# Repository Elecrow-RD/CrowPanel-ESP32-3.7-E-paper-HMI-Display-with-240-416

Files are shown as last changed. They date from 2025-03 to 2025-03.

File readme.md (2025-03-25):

### 1, Product picture

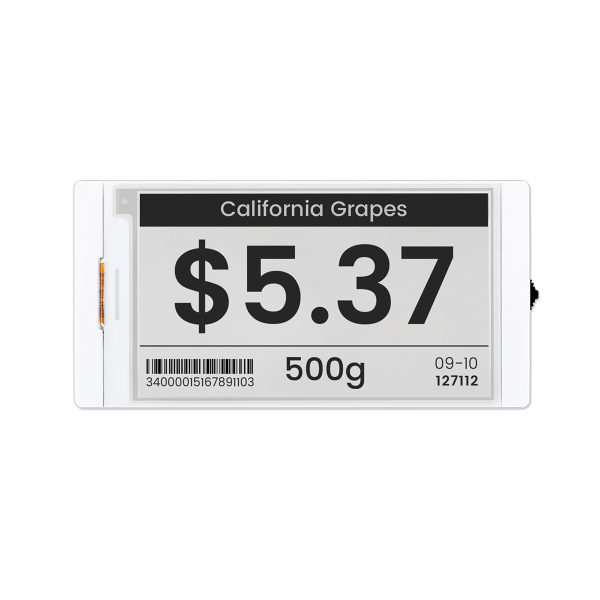
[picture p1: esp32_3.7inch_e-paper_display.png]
esp32_3.7inch_e-paper_display


### 2, Product version number

| | Hardware | Software | Remark |
| ---- | --- | --- | --- |
| 1 | V1.0 | V1.0 | latest |

### 3, product information

  - # Display Module Specifications

    - **Size**: 3.7 inch

    - **MCU**: ESP32-S3-WROOM-1-N8R8, up to 240 MHz

    - **Flash**: 8 MB

    - **PSRAM**: 8 MB

    - **Material**: Active Matrix Electrophoretic Display (AM EPD)

    - **Driver Chip**: UC8253

    - **Resolution**: 240(H)*416(V) Pixel

    - **Pixel Pitch**: 0.196*0.196

    - **Viewing Angle**: Full Viewing Angle

    - **Communication Interface**: 3-/4-wire SPI, default 4-wire SPI
  
    - **Interface**:
      
      - UART0 x1
      - BAT x1
      - GPIO x1
    
      - TF Card x1
    - **Button**:
      - Dial Switch x1
      - Menu Button  x1
      - Back Button x1
      - REST Button  x1
  
      - BOOT Button x1
- **Development Environment**: Arduino IDE、ESP IDF、MicroPython
    
- **Display Color**: Black and white
    
- **Refresh Mode**: Partial refresh (saves more power)
    
- **Display Operation Voltage**: 2.2~3.7V
    
- **Case**: White Acrylic Case
    
  - **Operation Temperature**: -0~50℃
    
  - **Storage Temperature**: -25~70℃
    
    - **Active Area**: 47.04(H)\*81.54(L) (H*L)

### 4, Use the driver module

| Name | dependency library |
| --- | --- |
| UC8253 | EPD<br />version=1.0.0 |

### 5,Quick Start

##### Arduino IDE starts

1.Download the library files used by this product to the 'libraries' folder.

C:\Users\Documents\Arduino\libraries\



2.Open the Arduino IDE

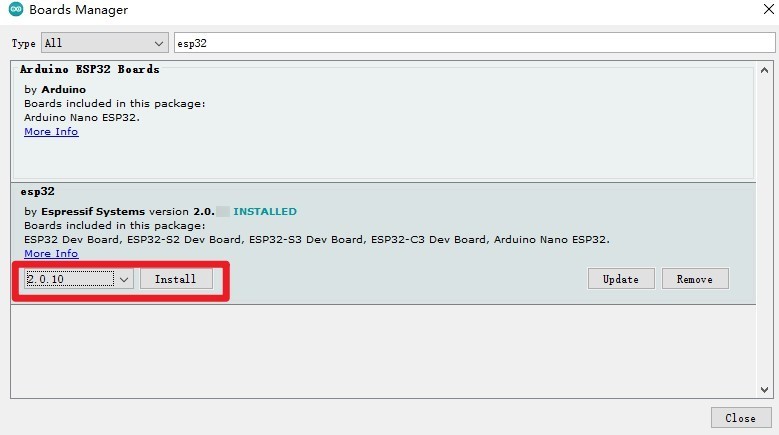
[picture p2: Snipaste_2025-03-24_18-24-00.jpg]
Snipaste_2025-03-24_18-24-00


3.Open the code configuration environment and burn it

setting

### 6,Folder structure.

|--3D file： Contains 3D model files (.stp) for the hardware. These files can be used for visualization, enclosure design, or integration into CAD software.

|--Datasheet: Includes datasheets for components used in the project, providing detailed specifications, electrical characteristics, and pin configurations.

|--Eagle_SCH&PCB: Contains **Eagle CAD** schematic (`.sch`) and PCB layout (`.brd`) files. These are used for circuit design and PCB manufacturing.

|--example: Provides example code and projects to demonstrate how to use the hardware and libraries. These examples help users get started quickly.

|--factory_firmware: Stores pre-compiled factory firmware that can be directly flashed onto the device. This ensures the device runs the default functionality.

|--factory_sourcecode: Contains the source code for the factory firmware, allowing users to modify and rebuild the firmware as needed.

### 7,Pin definition

#define SCK 12

#define MOSI 11

#define RES 47

#define DC 46

#define CS 45

#define BUSY 48

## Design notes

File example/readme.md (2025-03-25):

**Arduino**: This folder contains sample programs for the Arduino platform, which is known for its ease of use and versatility in creating interactive electronic projects.

#### NOTE!!!:When running this program , you need to download the officially provided libraries and place them in the libraries of arduino. esp32 version needs to be 2.0.10 the version of the libraries is the same as the officially provided version.

Link to the corresponding course wiki:https://www.elecrow.com/wiki/CrowPanel_ESP32_E-Paper_3.7-inch_Arduino_Tutorial.html

Video Tutorial Links：https://www.youtube.com/watch?v=smDFHRxDYdw

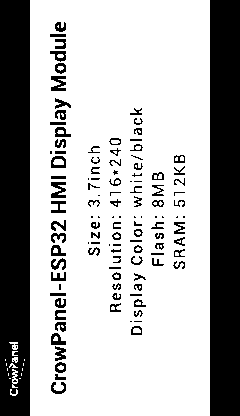
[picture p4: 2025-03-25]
factory_sourecode/3.7_tow/pic/IRAD_UI_3_7_参数介绍.bmp

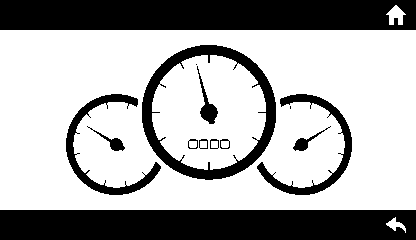
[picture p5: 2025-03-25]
factory_sourecode/3.7_tow/pic/new/NEW_UI_3-7_BW_img-03.bmp

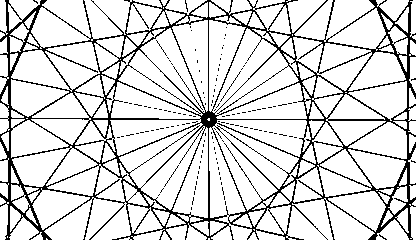
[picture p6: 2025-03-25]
factory_sourecode/3.7_tow/pic/IRAD_UI_3_7/IRAD_UI_3_7_图片案例-06.bmp

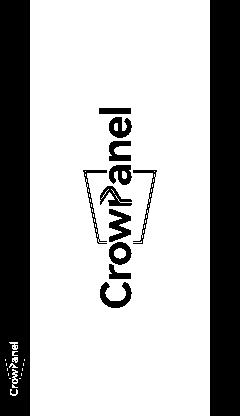
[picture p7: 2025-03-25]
factory_sourecode/3.7_tow/pic/IRAD_UI_3_7_开机界面.bmp

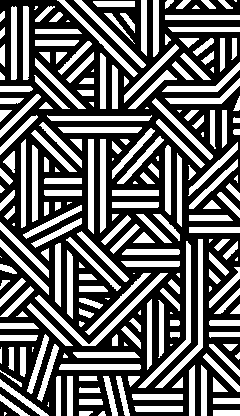
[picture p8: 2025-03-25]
factory_sourecode/3.7_tow/pic/IRAD_UI_3_7_图片案例-08.bmp

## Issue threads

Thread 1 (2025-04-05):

Wrong comments in TF example

05k4rausdertonne, 2025-04-05:
in the file example/arduino/Examples/3.7_TF/3.7_TF.ino on line 21-23 it says:
```.cpp
 // Initialize the screen backlight pin.
  pinMode(42, OUTPUT);
  digitalWrite(42, HIGH);  // Set the screen backlight pin to high to turn on the backlight.
```
however it should instead be

```.cpp
 // Initialize the TF card control pin.
  pinMode(42, OUTPUT);
  digitalWrite(42, HIGH);  // Set the TF card control pin to high to turn on the TF card.
```

since according to the schematic of the board io 42 is connected to TF_3.3_CTL

this cost me a whole day of error hunting btw. (because i'm stupid) so please update the code accordingly :)

Regards

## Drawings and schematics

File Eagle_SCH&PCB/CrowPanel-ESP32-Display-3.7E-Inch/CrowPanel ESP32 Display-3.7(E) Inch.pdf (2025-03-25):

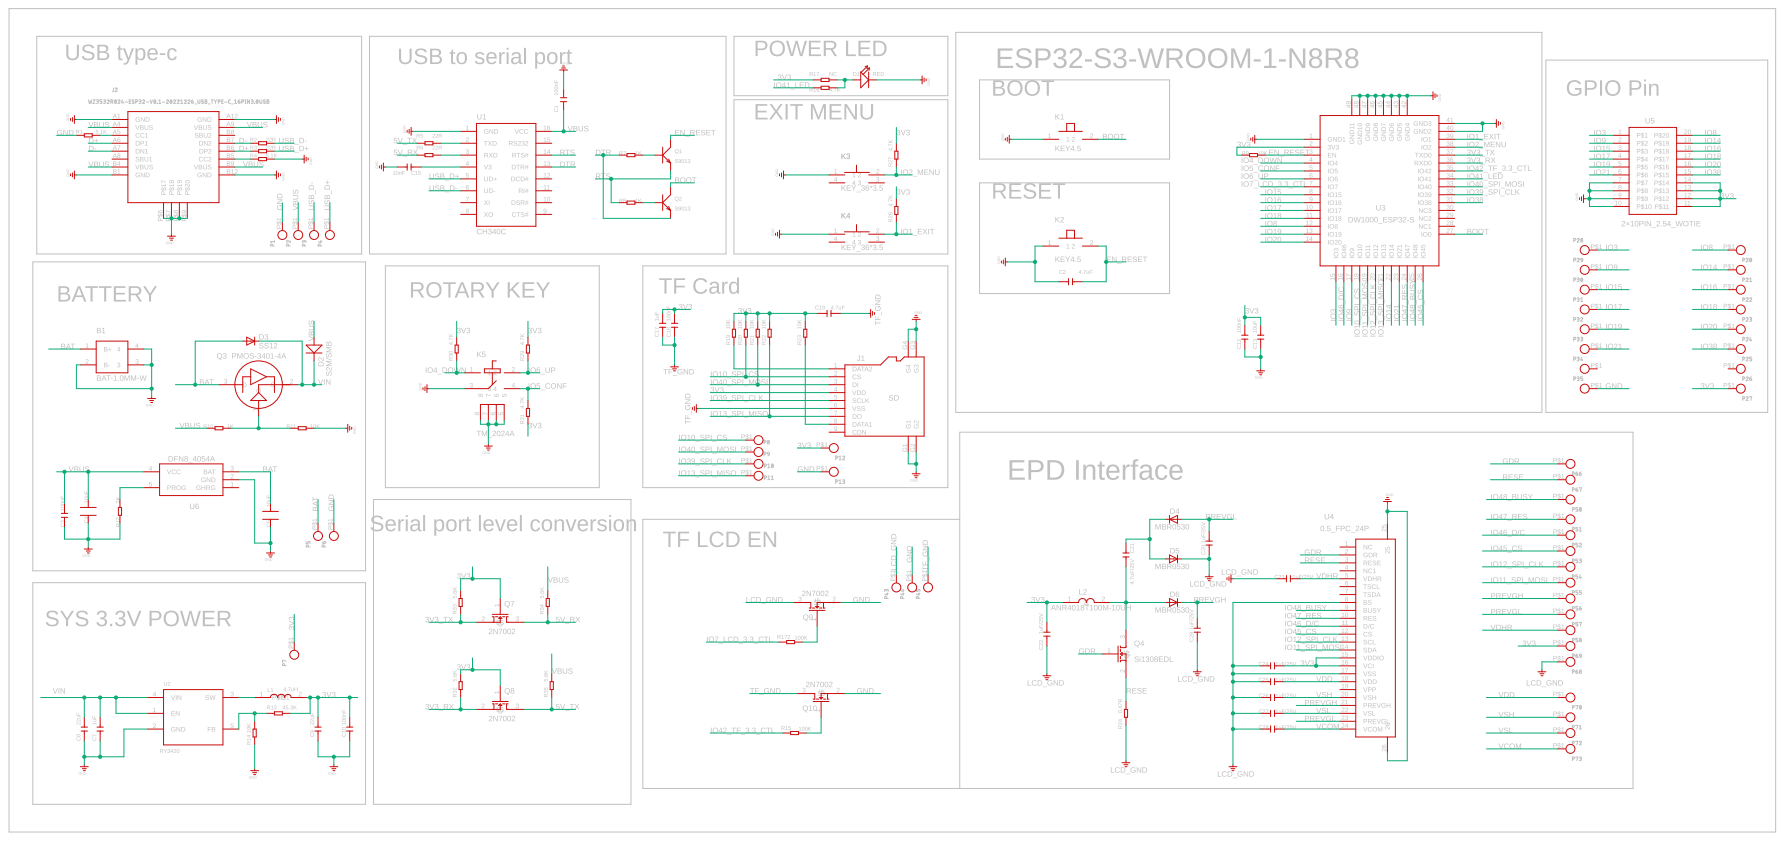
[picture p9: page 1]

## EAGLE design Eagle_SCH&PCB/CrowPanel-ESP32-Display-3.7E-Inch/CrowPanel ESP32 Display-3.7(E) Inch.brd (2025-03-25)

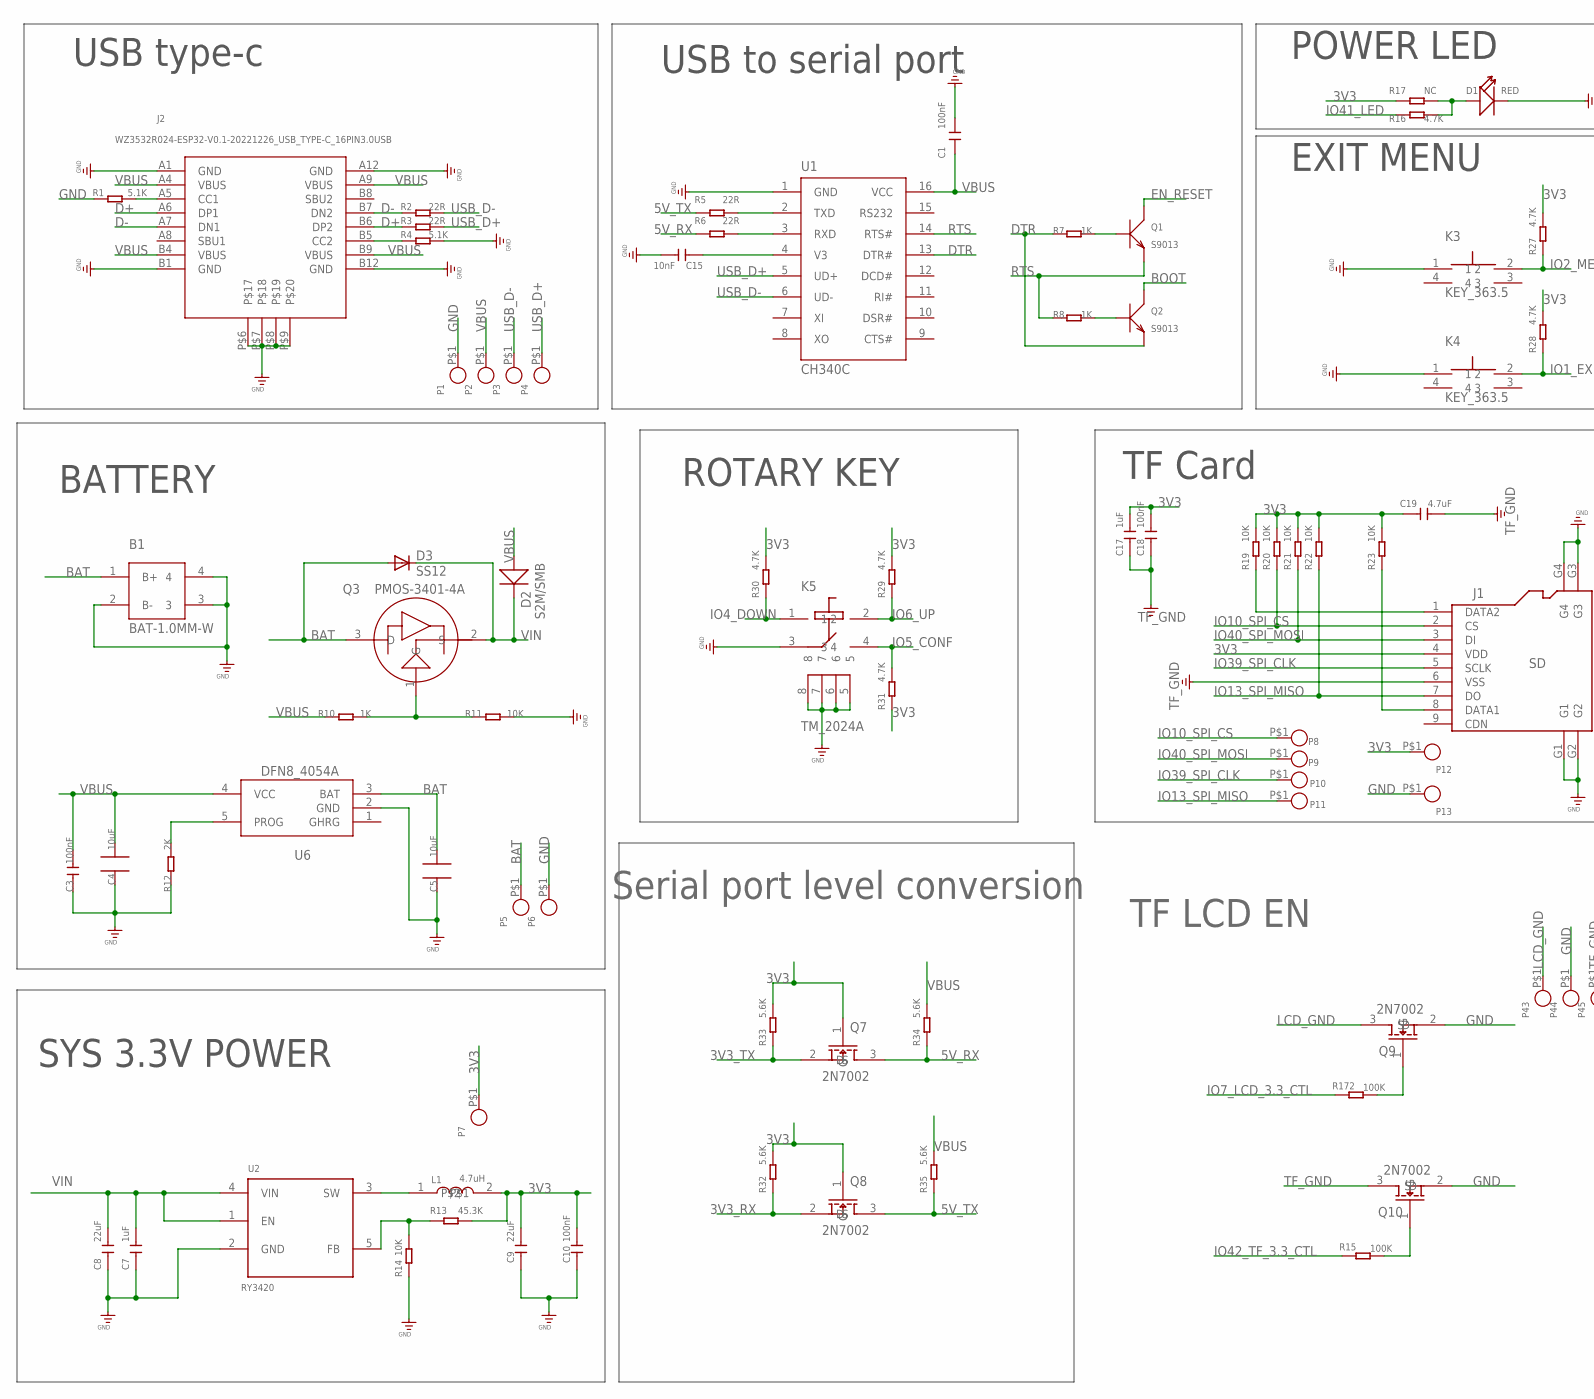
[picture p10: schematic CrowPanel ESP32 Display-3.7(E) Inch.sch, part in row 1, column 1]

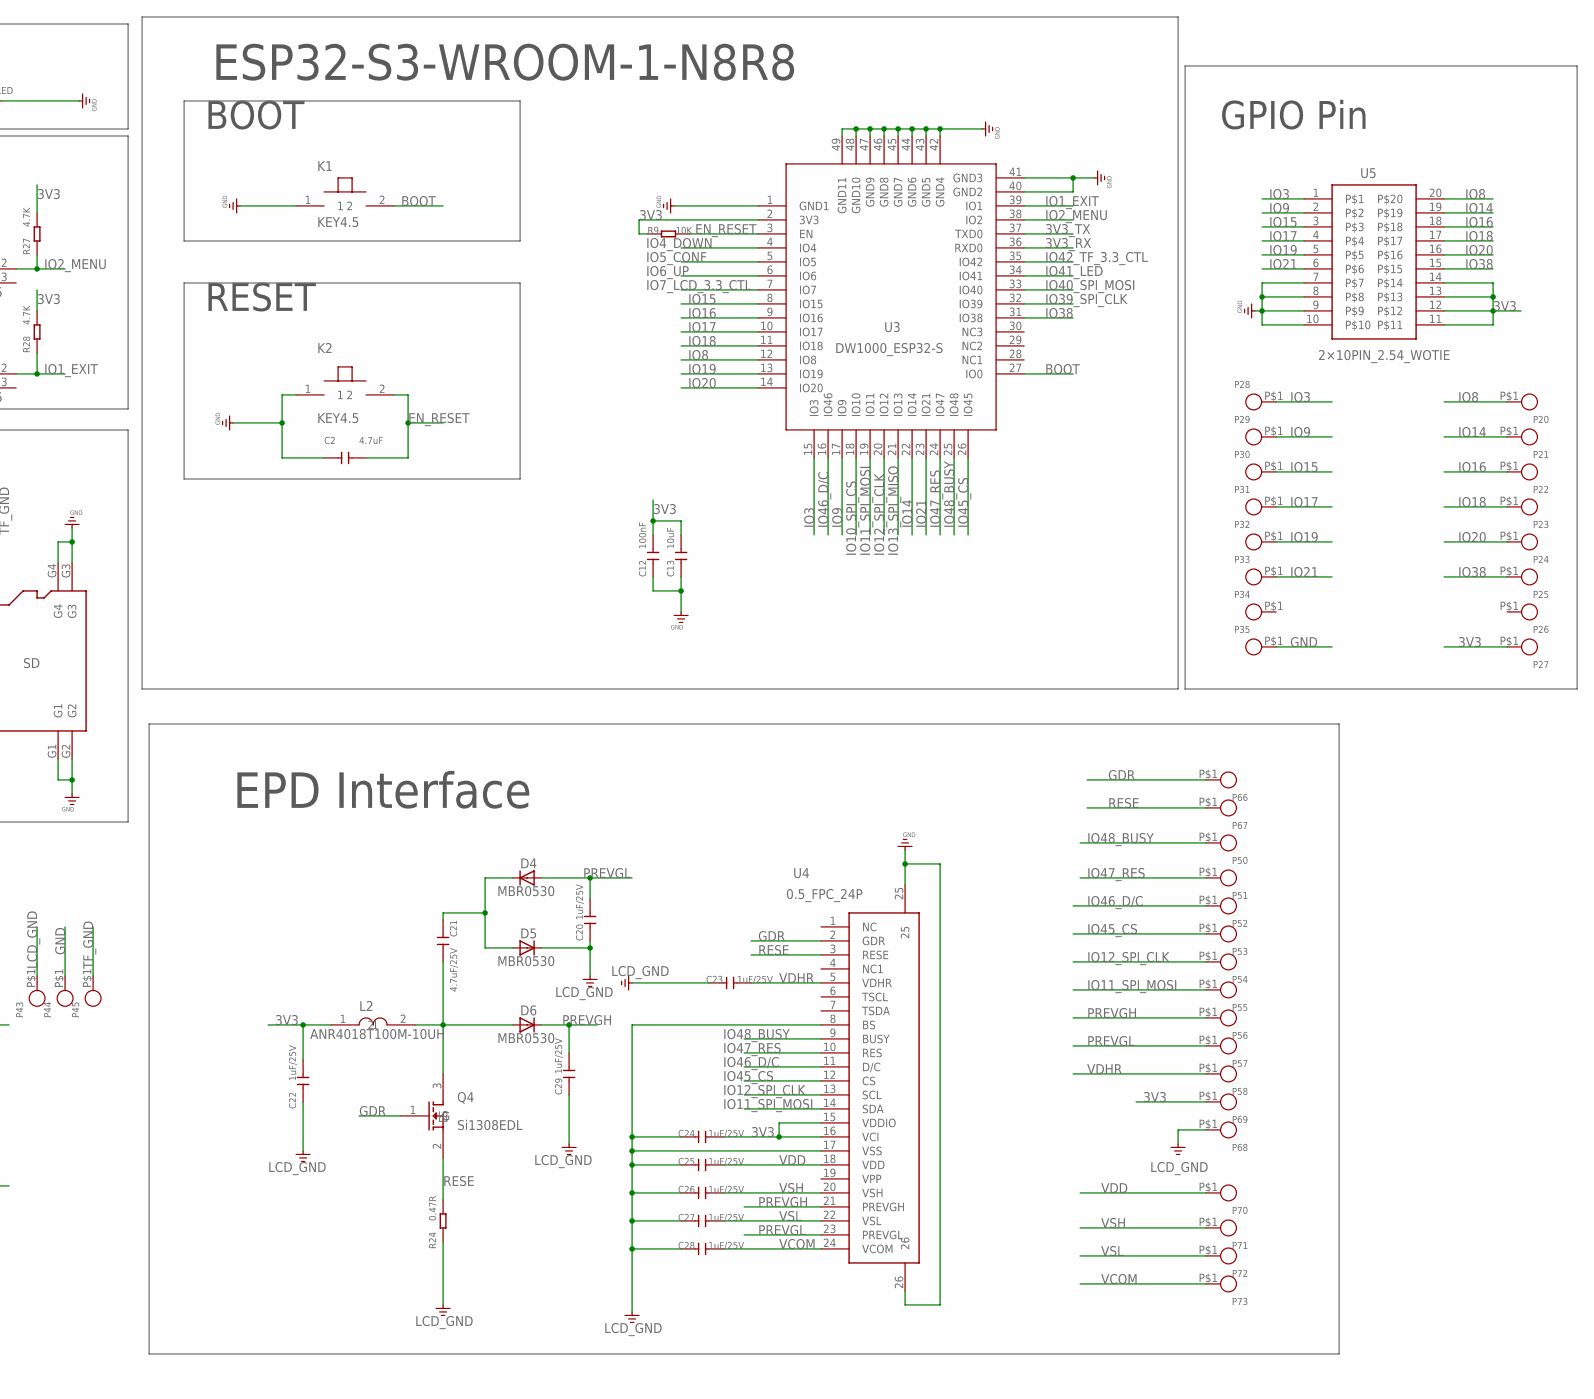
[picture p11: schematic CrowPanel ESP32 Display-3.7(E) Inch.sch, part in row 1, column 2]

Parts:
B1: BAT-1.0MM-W; SH1.0MM-W
C1: 100nF; 0603
C2: 4.7uF; A_XBJ_0603
C3, C12, C18: 100nF; A9G_DISCRETE_C0603
C4, C5: 10uF; CPT_SMD_0805_S
C7: 1uF; A_XBJ_0603
C8, C9: 22uF; A_XBJ_0805
C10: 100nF; A_XBJ_0603
C13: 10uF; A9G_DISCRETE_C0603
C15: 10nF; A_XBJ_0603
C17: 1uF; A9G_DISCRETE_C0603
C19: 4.7uF; A9G_DISCRETE_C0603
C20, C22, C23, C24, C25, C26, C27, C28, C29: 1uF/25V; A9G_DISCRETE_C0603
C21: 4.7uF/25V; A9G_DISCRETE_C0603
D1: RED; A_XBJ_DISCRETE_LED-0603
D2: S2M/SMB; DO-214AB_214AB
D3: SS12; DIODE_DO-214AC
D4, D5, D6: MBR0530; DIODE_SOD123
J1: SD; CONNECTOR_9P-SMD-W/-RING
J2: WZ3532R024-ESP32-V0.1-20221226_USB_TYPE-C_16PIN3.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; WZ3532R024-ESP32-V0.1-20221226_KEVIN_3.0TYPEC-SMD
K1, K2: KEY4.5; KEY-4.5
K3, K4: KEY_363.5; KEY_3*6*3.5
K5: TM_2024A
L1: 4.7uH; WZ2432R028-ESP32-V1.2-20231108_CD54_CD54
L2: ANR4018T100M-10UH; ANR4018
P1, P2, P3, P4, P5, P6, P7, P8, P9, P10, P11, P12, P13, P20, P21, P22, P23, P24, P25, P26, P27, P28, P29, P30, P31, P32, P33, P34, P35, P43, P44, P45, P50, P51, P52, P53, P54, P55, P56, P57, P58, P66, P67, P68, P69, P70, P71, P72, P73: CROWPI_POW_PADPAD-1.0MM; CROWPI_POW_PAD-1.0MM
Q1, Q2: S9013; DISCRETE_SOT23$1
Q3: PMOS-3401-4A; DFN8_SOT-23
Q4: Si1308EDL; SOT-323_W
Q7, Q8, Q9, Q10: 2N7002; SOT23-3_W
R1, R4: 5.1K; R0603
R2, R3, R5, R6: 22R; R0603
R7, R8, R10: 1K; A9G_DISCRETE_R0603
R9, R11, R14, R19, R20, R21, R22, R23: 10K; A9G_DISCRETE_R0603
R12: 2K; A9G_DISCRETE_R0603
R13: 45.3K; A9G_DISCRETE_R0603
R15, R172: 100K; R0603
R16, R27, R28, R29, R30, R31: 4.7K; A9G_DISCRETE_R0603
R17: NC; A9G_DISCRETE_R0603
R24: 0.47R; A9G_DISCRETE_R0603
R32, R33, R34, R35: 5.6K; DISCRETE_R0603
U1: CH340C; A_XBJ_SOP-16
U2: RY3420; CROWBOT_-V1.0-20220525_A_XBJ_SOT23-5
U3: DW1000_ESP32-S; DW1000_ESP32-S3
U4: 0.5_FPC_24P
U5: 2×10PIN_2.54_WOTIE; 2*10PIN_2.54_WOTIE
U6: DFN8_4054A; DFN8_SOP23-5

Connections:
3V3: C9.2, C10.2, C12.2, C13.2, C17.2, C18.2, C19.2, C22.2, C24.1, J1.4 (VDD), L1.2, L2.1, P7.P$1, P12.P$1, P27.P$1, P69.P$1, Q7.1 (G), Q8.1 (G), R9.1, R13.2, R17.1, R19.2, R20.2, R21.2, R22.2, R23.2, R27.2, R28.2, R29.2, R30.2, R31.1, R32.2, R33.2, U3.2 (3V3), U4.15 (VDDIO), U4.16 (VCI), U5.11, U5.12, U5.13, U5.14
3V3_RX: Q8.2 (S), R32.1, U3.36 (RXD0)
3V3_TX: Q7.2 (S), R33.1, U3.37 (TXD0)
5V_RX: Q7.3 (D), R6.1, R34.1
5V_TX: Q8.3 (D), R5.1, R35.1
BAT: B1.1 (B+), C5.2, D3.A, P5.P$1, Q3.3 (D), U6.3 (BAT)
BOOT: K1.2, Q2.3 (C), U3.27 (IO0)
D+: J2.A6 (DP1), J2.B6 (DP2), R3.1
D-: J2.A7 (DN1), J2.B7 (DN2), R2.1
DTR: Q2.2 (E), R7.1, U1.13 (DTR#)
EN_RESET: C2.2, K2.2, Q1.3 (C), R9.2, U3.3 (EN)
GDR: P66.P$1, Q4.1 (G), U4.2 (GDR)
GND: B1.2 (B-), B1.3, B1.4, C1.2, C2.1, C3.1, C4.1, C5.1, C7.1, C8.1, C9.1, C10.1, C12.1, C13.1, C15.2, D1.-, J1.G1, J1.G2, J1.G3, J1.G4, J2.A1 (GND), J2.A12 (GND), J2.B1 (GND), J2.B12 (GND), J2.P$6, J2.P$7, J2.P$8, J2.P$9, K1.1, K2.1, K3.1, K4.1, K5.3, K5.5, K5.6, K5.7, K5.8, P1.P$1, P6.P$1, P13.P$1, P35.P$1, P44.P$1, Q9.2 (S), Q10.2 (S), R1.1, R4.2, R11.2, R12.1, R14.1, U1.1 (GND), U2.2 (GND), U3.1 (GND1), U3.40 (GND2), U3.41 (GND3), U3.42 (GND4), U3.43 (GND5), U3.44 (GND6), U3.45 (GND7), U3.46 (GND8), U3.47 (GND9), U3.48 (GND10), U3.49 (GND11), U4.25, U4.26, U5.7, U5.8, U5.9, U5.10, U6.2 (GND)
IO1_EXIT: K4.2, R28.1, U3.39 (IO1)
IO2_MENU: K3.2, R27.1, U3.38 (IO2)
IO3: P28.P$1, U3.15 (IO3), U5.1
IO4_DOWN: K5.1, R30.1, U3.4 (IO4)
IO5_CONF: K5.4, R31.2, U3.5 (IO5)
IO6_UP: K5.2, R29.1, U3.6 (IO6)
IO7_LCD_3.3_CTL: R172.1, U3.7 (IO7)
IO8: P20.P$1, U3.12 (IO8), U5.20
IO9: P29.P$1, U3.17 (IO9), U5.2
IO10_SPI_CS: J1.2 (CS), P8.P$1, R20.1, U3.18 (IO10)
IO11_SPI_MOSI: P55.P$1, U3.19 (IO11), U4.14 (SDA)
IO12_SPI_CLK: P54.P$1, U3.20 (IO12), U4.13 (SCL)
IO13_SPI_MISO: J1.7 (DO), P11.P$1, R22.1, U3.21 (IO13)
IO14: P21.P$1, U3.22 (IO14), U5.19
IO15: P30.P$1, U3.8 (IO15), U5.3
IO16: P22.P$1, U3.9 (IO16), U5.18
IO17: P31.P$1, U3.10 (IO17), U5.4
IO18: P23.P$1, U3.11 (IO18), U5.17
IO19: P32.P$1, U3.13 (IO19), U5.5
IO20: P24.P$1, U3.14 (IO20), U5.16
IO21: P33.P$1, U3.23 (IO21), U5.6
IO38: P25.P$1, U3.31 (IO38), U5.15
IO39_SPI_CLK: J1.5 (SCLK), P10.P$1, U3.32 (IO39)
IO40_SPI_MOSI: J1.3 (DI), P9.P$1, R21.1, U3.33 (IO40)
IO41_LED: R16.1, U3.34 (IO41)
IO42_TF_3.3_CTL: R15.1, U3.35 (IO42)
IO45_CS: P53.P$1, U3.26 (IO45), U4.12 (CS)
IO46_D/C: P52.P$1, U3.16 (IO46), U4.11 (D/C)
IO47_RES: P51.P$1, U3.24 (IO47), U4.10 (RES)
IO48_BUSY: P50.P$1, U3.25 (IO48), U4.9 (BUSY)
LCD_GND: C20.1, C22.1, C23.2, C24.2, C25.2, C26.2, C27.2, C28.2, C29.1, D5.C, P43.P$1, P68.P$1, Q9.3 (D), R24.1, U4.8 (BS), U4.17 (VSS)
unnamed: Q1.1 (B), R7.2
unnamed: R5.2, U1.2 (TXD)
unnamed: R6.2, U1.3 (RXD)
unnamed: Q2.1 (B), R8.2
unnamed: J2.A5 (CC1), R1.2
unnamed: Q3.1 (G), R10.2, R11.1
unnamed: Q9.1 (G), R172.2
unnamed: Q10.1 (G), R15.2
unnamed: R13.1, R14.2, U2.5 (FB)
unnamed: J1.1 (DATA2), R19.1
unnamed: L1.1, U2.3 (SW)
unnamed: J2.B5 (CC2), R4.1
unnamed: C15.1, U1.4 (V3)
unnamed: R12.2, U6.5 (PROG)
unnamed: J1.8 (DATA1), R23.1
unnamed: D1.+, R16.2, R17.2
unnamed: C21.1, D4.C, D5.A
unnamed: C21.2, D6.A, L2.2, Q4.3 (D)
PREVGH: C29.2, D6.C, P56.P$1, U4.21 (PREVGH)
PREVGL: C20.2, D4.A, P57.P$1, U4.23 (PREVGL)
RESE: P67.P$1, Q4.2 (S), R24.2, U4.3 (RESE)
RTS: Q1.2 (E), R8.1, U1.14 (RTS#)
TF_GND: C17.1, C18.1, C19.1, J1.6 (VSS), P45.P$1, Q10.3 (D)
USB_D+: P4.P$1, R3.2, U1.5 (UD+)
USB_D-: P3.P$1, R2.2, U1.6 (UD-)
VBUS: C1.1, C3.2, C4.2, D2.1 (+), J2.A4 (VBUS), J2.A9 (VBUS), J2.B4 (VBUS), J2.B9 (VBUS), P2.P$1, R10.1, R34.2, R35.2, U1.16 (VCC), U6.4 (VCC)
VCOM: C28.1, P73.P$1, U4.24 (VCOM)
VDD: C25.1, P70.P$1, U4.18 (VDD)
VDHR: C23.1, P58.P$1, U4.5 (VDHR)
VIN: C7.2, C8.2, D2.2 (-), D3.C, Q3.2 (S), U2.1 (EN), U2.4 (VIN)
VSH: C26.1, P71.P$1, U4.20 (VSH)
VSL: C27.1, P72.P$1, U4.22 (VSL)

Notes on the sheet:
USB type-c
USB to serial port
POWER LED
EXIT MENU
ESP32-S3-WROOM-1-N8R8
GPIO Pin
EPD Interface
TF Card
ROTARY KEY
SYS 3.3V POWER
BATTERY
BOOT
RESET
Serial port level conversion
TF LCD EN

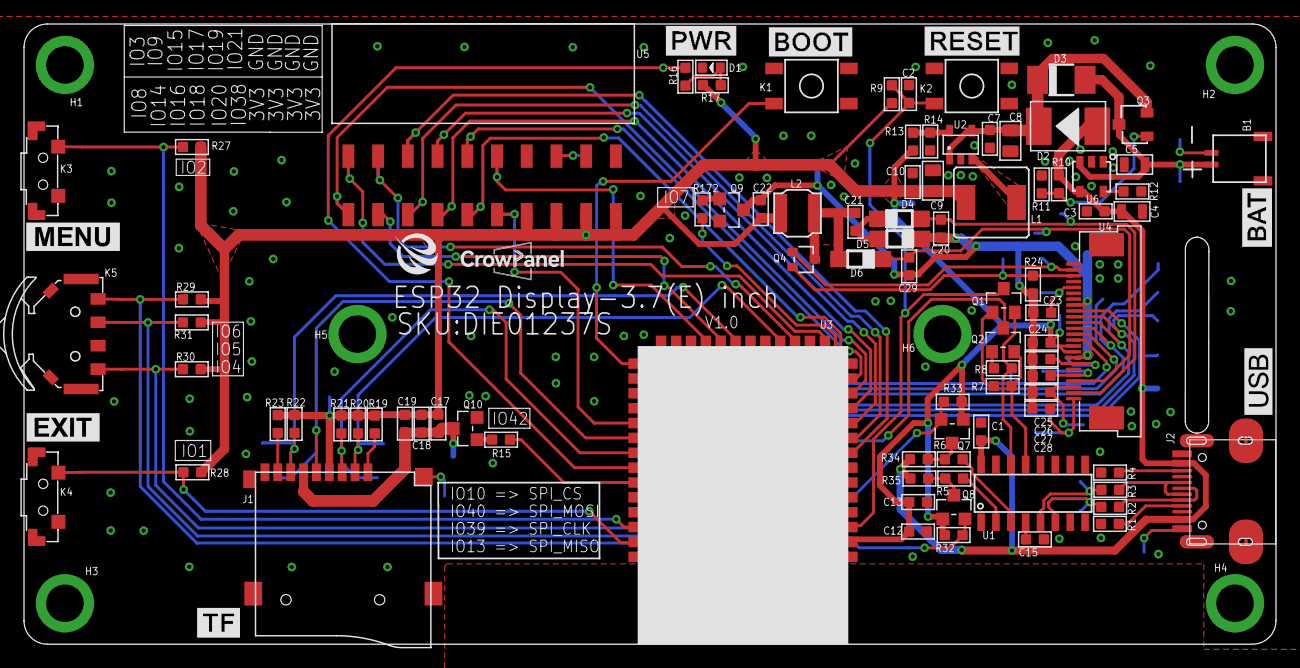
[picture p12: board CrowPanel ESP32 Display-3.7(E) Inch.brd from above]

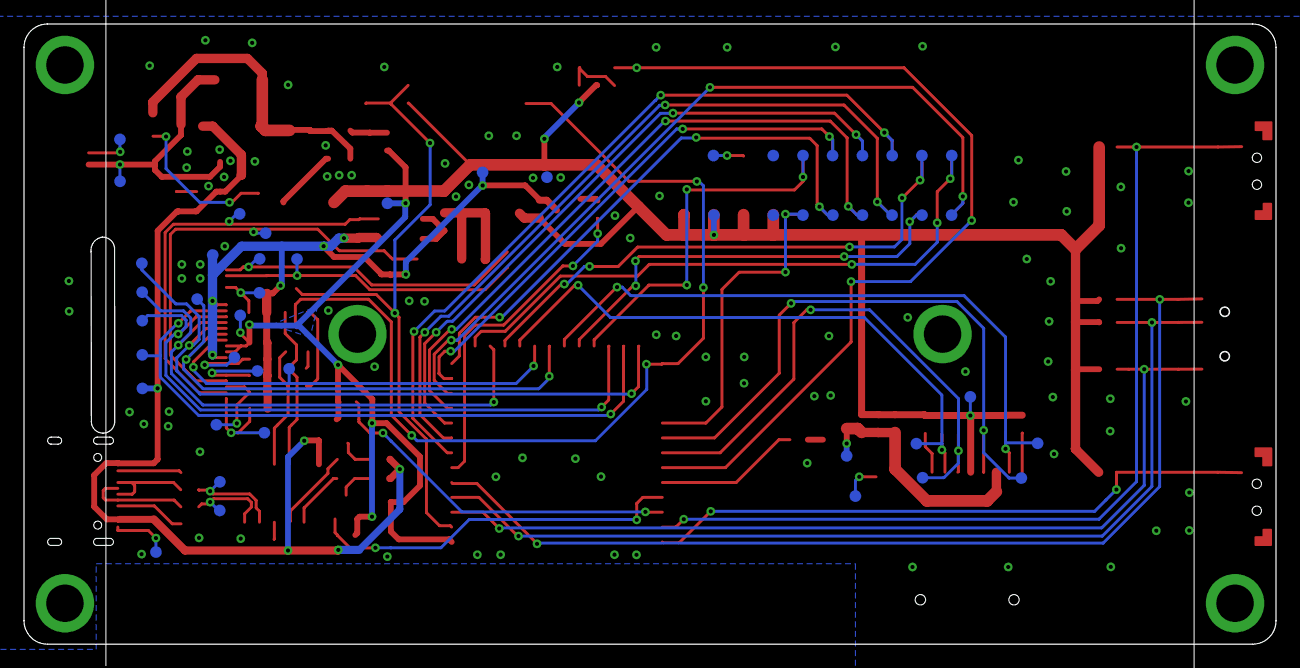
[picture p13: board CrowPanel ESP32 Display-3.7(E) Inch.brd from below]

Board: 2 copper layers, 107.0 x 53.0 mm, 139 parts (49 on the bottom side), 76 nets.

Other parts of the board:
U$30: LOGO-1
U$42: LOGO-MIN

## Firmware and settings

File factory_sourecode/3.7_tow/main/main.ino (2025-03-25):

#include <Arduino.h>
#include "EPD.h"
#include "EPD_GUI.h"
#include "Pic_boot_screen.h"
#include "pic_menu.h"
#include "pic_home.h"
#include "pic_description.h"
#include "pic_image.h"
#include "pic_scenario.h"

#include "FS.h"
#include "SD.h"
#include <WiFi.h>

#define FILE_NAME "/book.txt"
#define SD_MOSI 40
#define SD_MISO 13
#define SD_SCK 39
#define SD_CS 10
SPIClass SD_SPI = SPIClass(HSPI);

#include "BLEDevice.h"              //BLE驱动库
#include "BLEServer.h"              //BLE蓝牙服务器库
#include "BLEUtils.h"               //BLE实用程序库
#include "BLE2902.h"                //特征添加描述符库
BLECharacteristic *pCharacteristic;
BLEServer *pServer;
BLEService *pService;
bool deviceConnected = false;
char BLEbuf[32] = {0};
uint32_t cnt = 0;

#define SERVICE_UUID           "6E400001-B5A3-F393-E0A9-E50E24DCCA9E" // UART service UUID
#define CHARACTERISTIC_UUID_RX "6E400002-B5A3-F393-E0A9-E50E24DCCA9E"
#define CHARACTERISTIC_UUID_TX "6E400003-B5A3-F393-E0A9-E50E24DCCA9E"

class MyServerCallbacks: public BLEServerCallbacks {
    void onConnect(BLEServer* pServer) {
      deviceConnected = true;
      Serial.println("------> BLE connect .");
    };

    void onDisconnect(BLEServer* pServer) {
      deviceConnected = false;
      Serial.println("------> BLE disconnect .");
      pServer->startAdvertising(); // restart advertising
      Serial.println("start advertising");
    }
};

class MyCallbacks: public BLECharacteristicCallbacks {
    void onWrite(BLECharacteristic *pCharacteristic) {
      std::string rxValue = pCharacteristic->getValue();

      if (rxValue.length() > 0) {
        Serial.print("------>Received Value: ");

        for (int i = 0; i < rxValue.length(); i++) {
          Serial.print(rxValue[i]);
        }
        Serial.println();

        if (rxValue.find("A") != -1) {
          Serial.print("Rx A!");
        }
        else if (rxValue.find("B") != -1) {
          Serial.print("Rx B!");
        }
        Serial.println();
      }
    }
};

//打印唤醒原因
void print_wakeup_reason() {
  esp_sleep_wakeup_cause_t wakeup_reason;

  wakeup_reason = esp_sleep_get_wakeup_cause();

  switch (wakeup_reason)
  {
    case ESP_SLEEP_WAKEUP_EXT0 : Serial.println("Wakeup caused by external signal using RTC_IO"); break;
    case ESP_SLEEP_WAKEUP_EXT1 : Serial.println("Wakeup caused by external signal using RTC_CNTL"); break;
    case ESP_SLEEP_WAKEUP_TIMER : Serial.println("Wakeup caused by timer"); break;
    case ESP_SLEEP_WAKEUP_TOUCHPAD : Serial.println("Wakeup caused by touchpad"); break;
    case ESP_SLEEP_WAKEUP_ULP : Serial.println("Wakeup caused by ULP program"); break;
    default : Serial.printf("Wakeup was not caused by deep sleep: %d\n", wakeup_reason); break;
  }
}

//主页键
#define HOME_KEY 2
//退出键
#define EXIT_KEY 1

//轮播开关
//上一页
#define PRV_KEY 6
//下一页
#define NEXT_KEY 4
//确认
#define OK_KEY 5

int peg_pos;  //页游标
int slide_pos; //界面游标
int8_t prv_menu_pos;
int three_interface_flag; //三级界面标志
int scenario_ctl;  //开关标志
int scenario_ctl1;
int scenario_ctl2;
int scenario_ctl3;
int scenario_ctl4;
int sleep_num; //进去睡眠计数
bool test_flag;
char val;
int KEY_NUM;

uint8_t ImageBW[12480];

void clear_all()
{
  Paint_NewImage(ImageBW, EPD_W, EPD_H, Rotation, WHITE);
  Paint_Clear(WHITE); //清空画布
  EPD_FastInit();
  EPD_Display_Clear();
  EPD_Update();  //局刷之前先对E-Paper进行清屏操作
}

void clear_all1()
{
  Paint_NewImage(ImageBW, EPD_W, EPD_H, Rotation, WHITE);
  Paint_Clear(WHITE); //清空画布
  EPD_PartInit();
  EPD_Display_Clear();
  EPD_Update();  //局刷之前先对E-Paper进行清屏操作
}

int KEY_SCAN()
{

  if (test_flag != false)
  {
    //    Serial.println(" ....... ");
    return 0;
  }

  KEY_NUM = 0;
  if (digitalRead(HOME_KEY) == 0)
  {
    delay(50);
    int i = 0;
    if (digitalRead(HOME_KEY) == 0)
    {
      Serial.println("HOME_KEY");
      sleep_num = 0;
      Serial.println("sleep now clear");
      while (digitalRead(HOME_KEY) == 0)  //长按5s清屏
      {
        i++;
        Serial.print("HOME_KEY KEEP ");
        Serial.println(i);
        delay(10);
        if (i == 500)
        {
          Serial.println("Display_Clear ....... ");
          clear_all();
          EPD_DeepSleep();
          while(1);
          return 0;
        }
      }
      KEY_NUM = 1;
    }
  }
  else if (digitalRead(EXIT_KEY) == 0)
  {
    delay(50);
    if (digitalRead(EXIT_KEY) == 0)
    {
      Serial.println("EXIT_KEY");
      KEY_NUM = 2;
    }
  }
  else if (digitalRead(PRV_KEY) == 0)
  {
    delay(50);
    if (digitalRead(PRV_KEY) == 0)
    {
      Serial.println("PRV_KEY");
      KEY_NUM = 3;
    }
  }
  else if (digitalRead(NEXT_KEY) == 0)
  {
    delay(50);
    if (digitalRead(NEXT_KEY) == 0)
    {
      Serial.println("NEXT_KEY");
      KEY_NUM = 4;
    }
  }
  else if (digitalRead(OK_KEY) == 0)
  {
    delay(50);
    if (digitalRead(OK_KEY) == 0)
    {
      Serial.println("OK_KEY");
      KEY_NUM = 5;
    }
  }

  return KEY_NUM;
}

void show_home_menu()
{
  clear_all();
  EPD_PartInit();
  EPD_ShowPicture(0, 0, EPD_W, EPD_H, gImage_menu, WHITE);
  EPD_Display(ImageBW);
  EPD_Update();
  EPD_DeepSleep();

  peg_pos = 1;
  slide_pos = 0;
  prv_menu_pos = 0;
}

void show_home_menu1()
{
  clear_all();
  EPD_PartInit();
  EPD_ShowPicture(0, 0, EPD_W, EPD_H, gImage_menu1, WHITE);
  EPD_Display(ImageBW);
  EPD_Update();
  EPD_DeepSleep();

  peg_pos = 1;
  slide_pos = 1;
  prv_menu_pos = 1;
}

void show_home_menu2()
{
  clear_all();
  EPD_PartInit();
  EPD_ShowPicture(0, 0, EPD_W, EPD_H, gImage_menu2, WHITE);
  EPD_Display(ImageBW);
  EPD_Update();
  EPD_DeepSleep();

  peg_pos = 1;
  slide_pos = 2;
  prv_menu_pos = 2;
}

void show_home_menu_pos(int show_pos)
{
  switch (show_pos)
  {
    case 0:
      EPD_PartInit();
      EPD_ShowPicture(0, 0, EPD_W, EPD_H, gImage_menu, WHITE);
      EPD_Display(ImageBW);
      EPD_Update();
      EPD_DeepSleep();

      peg_pos = 1;
      slide_pos = 0;
      prv_menu_pos = 0;
      break;
    case 1:
      EPD_PartInit();
      EPD_ShowPicture(0, 0, EPD_W, EPD_H, gImage_menu1, WHITE);
      EPD_Display(ImageBW);
      EPD_Update();
      EPD_DeepSleep();

      peg_pos = 1;
      slide_pos = 1;
      prv_menu_pos = 1;
      break;
    case 2:
      EPD_PartInit();
      EPD_ShowPicture(0, 0, EPD_W, EPD_H, gImage_menu2, WHITE);
      EPD_Display(ImageBW);
      EPD_Update();
      EPD_DeepSleep();

      peg_pos = 1;
      slide_pos = 2;
      prv_menu_pos = 2;
      break;
    default:
      break;
  }
}

void show_description(int show_pos)
{
  if (show_pos == 0)
  {
    slide_pos = 0;
  }
  switch (show_pos)
  {
    case 0:
      //第一页介绍
      //      clear_all1();
      EPD_FastInit();
      EPD_ShowPicture(0, 0, EPD_W, EPD_H, gImage_description, WHITE);
      EPD_Display(ImageBW);
      EPD_Update();
      EPD_DeepSleep();

      peg_pos = 2;
      slide_pos = 0;
      prv_menu_pos = 0;
      three_interface_flag = 0;
      test_flag = false;

      break;
    case 1:
      //      clear_all1();
      EPD_FastInit();
      EPD_ShowPicture(0, 0, EPD_W, EPD_H, gImage_description1, WHITE);
      EPD_Display(ImageBW);
      EPD_Update();
      EPD_DeepSleep();

      peg_pos = 2;
      slide_pos = 1;
      prv_menu_pos = 0;
      three_interface_flag = 0;
      test_flag = false;

      break;
    case 2:
      //      clear_all1();
      EPD_FastInit();
      EPD_ShowPicture(0, 0, EPD_W, EPD_H, gImage_description2, WHITE);
      EPD_Display(ImageBW);
      EPD_Update();
      EPD_DeepSleep();

      peg_pos = 2;
      slide_pos = 2;
      prv_menu_pos = 0;
      three_interface_flag = 0;
      test_flag = false;

      break;
    case 3:
      //      clear_all1();
      EPD_FastInit();
      EPD_ShowPicture(0, 0, EPD_W, EPD_H, gImage_description3, WHITE);
      EPD_Display(ImageBW);
      EPD_Update();
      EPD_DeepSleep();

      peg_pos = 2;
      slide_pos = 3;
      prv_menu_pos = 0;
      three_interface_flag = 0;
      test_flag = false;

      break;
    default:
      break;
  }
}

void show_image_example(int show_pos)
{
  if (show_pos == 0)
  {
    slide_pos = 0;
  }
  switch (show_pos)
  {
    case 0:
//      clear_all1();
      EPD_FastInit();
      EPD_ShowPicture(0, 0, EPD_W, EPD_H, gImage_image, WHITE);
      EPD_Display(ImageBW);
      EPD_Update();
      EPD_DeepSleep();

      peg_pos = 2;
      prv_menu_pos = 1;
      slide_pos = 0;
      three_interface_flag = 1;
      test_flag = false;
      break;
    case 1:
//      clear_all1();
      EPD_FastInit();
      EPD_ShowPicture(0, 0, EPD_W, EPD_H, gImage_image1, WHITE);
      EPD_Display(ImageBW);
      EPD_Update();
      EPD_DeepSleep();

      peg_pos = 2;
      prv_menu_pos = 1;
      slide_pos = 1;
      three_interface_flag = 1;
      test_flag = false;
      break;
    case 2:
//      clear_all1();
      EPD_FastInit();
      EPD_ShowPicture(0, 0, EPD_W, EPD_H, gImage_image2, WHITE);
      EPD_Display(ImageBW);
      EPD_Update();
      EPD_DeepSleep();

      peg_pos = 2;
      prv_menu_pos = 1;
      slide_pos = 2;
      three_interface_flag = 1;
      test_flag = false;
      break;
    case 3:
//      clear_all1();
      EPD_FastInit();
      EPD_ShowPicture(0, 0, EPD_W, EPD_H, gImage_image3, WHITE);
      EPD_Display(ImageBW);
      EPD_Update();
      EPD_DeepSleep();

      peg_pos = 2;
      prv_menu_pos = 1;
      slide_pos = 3;
      three_interface_flag = 1;
      test_flag = false;
      break;
    case 4:
//      clear_all1();
      EPD_FastInit();
      EPD_ShowPicture(0, 0, EPD_W, EPD_H, gImage_image4, WHITE);
      EPD_Display(ImageBW);
      EPD_Update();
      EPD_DeepSleep();

      peg_pos = 2;
      prv_menu_pos = 1;
      slide_pos = 4;
      three_interface_flag = 1;
      test_flag = false;
      break;
    case 5:
//      clear_all1();
      EPD_FastInit();
      EPD_ShowPicture(0, 0, EPD_W, EPD_H, gImage_image5, WHITE);
      EPD_Display(ImageBW);
      EPD_Update();
      EPD_DeepSleep();

      peg_pos = 2;
      prv_menu_pos = 1;
      slide_pos = 5;
      three_interface_flag = 1;
      test_flag = false;
      break;
    case 6:
//      clear_all1();
      EPD_FastInit();
      EPD_ShowPicture(0, 0, EPD_W, EPD_H, gImage_image6, WHITE);
      EPD_Display(ImageBW);
      EPD_Update();
      EPD_DeepSleep();

      peg_pos = 2;
      prv_menu_pos = 1;
      slide_pos = 6;
      three_interface_flag = 1;
      test_flag = false;
      break;
    default:
      break;
  }
}

void show_scenario_example_pos(int show_pos)  //scenario 显示游标
{
  if (show_pos == 0)
  {
    slide_pos = 0;
  }
  switch (show_pos)
  {
    case 0:
      EPD_FastInit();
      EPD_ShowPicture(40, 388, 160, 8, gImage_scenario_pos, WHITE);
      EPD_Display(ImageBW);
      EPD_Update();
      EPD_DeepSleep();

      slide_pos = 0;
      peg_pos = 2;
      prv_menu_pos = 2;
      three_interface_flag = 2;
      test_flag = false;
      break;
    case 1:
      EPD_FastInit();
      EPD_ShowPicture(40, 388, 160, 8, gImage_scenario_pos1, WHITE);
      EPD_Display(ImageBW);
      EPD_Update();
      EPD_DeepSleep();

      slide_pos = 1;
      peg_pos = 2;
      prv_menu_pos = 2;
      three_interface_flag = 2;
      test_flag = false;
      break;
    case 2:
      EPD_FastInit();
      EPD_ShowPicture(40, 388, 160, 8, gImage_scenario_pos2, WHITE);
      EPD_Display(ImageBW);
      EPD_Update();
      EPD_DeepSleep();

      slide_pos = 2;
      peg_pos = 2;
      prv_menu_pos = 2;
      three_interface_flag = 2;
      test_flag = false;
      break;
    case 3:
      EPD_FastInit();
      EPD_ShowPicture(40, 388, 160, 8, gImage_scenario_pos3, WHITE);
      EPD_Display(ImageBW);
      EPD_Update();
      EPD_DeepSleep();

      slide_pos = 3;
      peg_pos = 2;
      prv_menu_pos = 2;
      three_interface_flag = 2;
      test_flag = false;
      break;
    case 4:
      EPD_FastInit();
      EPD_ShowPicture(40, 388, 160, 8, gImage_scenario_pos4, WHITE);
      EPD_Display(ImageBW);
      EPD_Update();
      EPD_DeepSleep();

      slide_pos = 4;
      prv_menu_pos = 2;
      peg_pos = 2;
      three_interface_flag = 2;
      test_flag = false;
      break;
    default:
      break;
  }
}
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
void loop()
{
  //  Serial.println("******************************  home");
  //测试串口检测
  test_task();
  if (KEY_SCAN() != 0 && test_flag == false)
  {
    sleep_num = 0;
    Serial.print("KEY_NUM CODE: ");
    Serial.println(KEY_NUM);
    switch (KEY_NUM)
    {
      case 1:
        //返回主页
        //        clear_all();
        show_home_menu();
        Serial.println("return home");
        three_interface_flag = 0;
        scenario_ctl = 0;
        scenario_ctl1 = 0;
        scenario_ctl2 = 0;
        scenario_ctl3 = 0;
        scenario_ctl4 = 0;
        peg_pos = 1; //进入2级界面，功能页选择
        slide_pos = 0;
        prv_menu_pos = 0;
        three_interface_flag = 0;
        Serial.print("peg_pos : ");
        Serial.println(peg_pos);
        break;
      case 2:
        //返回
        if (peg_pos == 1 || peg_pos == 2)
        {
          peg_pos = 1;
          if (prv_menu_pos == 0)
          {
            slide_pos = 0;
            prv_menu_pos = 0;
            three_interface_flag = 0;
            scenario_ctl = 0;
            scenario_ctl1 = 0;
            scenario_ctl2 = 0;
            scenario_ctl3 = 0;
            scenario_ctl4 = 0;
            show_home_menu();
          }
          else if (prv_menu_pos == 1)
          {
            slide_pos = 1;
            prv_menu_pos = 1;
            three_interface_flag = 0;
            scenario_ctl = 0;
            scenario_ctl1 = 0;
            scenario_ctl2 = 0;
            scenario_ctl3 = 0;
            scenario_ctl4 = 0;
            show_home_menu1();
          }
          else if (prv_menu_pos == 2)
          {
            slide_pos = 2;
            prv_menu_pos = 2;
            three_interface_flag = 0;
            scenario_ctl = 0;
            scenario_ctl1 = 0;
            scenario_ctl2 = 0;
            scenario_ctl3 = 0;
            scenario_ctl4 = 0;
            show_home_menu2();
          }
        }
        break;
      case 3:
        //2级界面上滑
        if (peg_pos == 1)
        {
          slide_pos = slide_pos - 1;
          if (slide_pos < 0)
          {
            slide_pos = 0;
            return ;
          }
          Serial.print("show_home_menu_pos-> slide_pos : ");
          Serial.println(slide_pos);
          Serial.println("");
          show_home_menu_pos(slide_pos);
        }
        //在3级界面上滑
        else if (peg_pos == 2)
        {
          slide_pos = slide_pos - 1;
          if (slide_pos < 0)
          {
            slide_pos = 0;
            return ;
          }
          if (three_interface_flag == 0)
          {
            Serial.print("show_description-> slide_pos : ");
            Serial.println(slide_pos);
            Serial.println("");
            show_description(slide_pos);
          }
          else if (three_interface_flag == 1)
          {
            Serial.print("show_image_example-> slide_pos : ");
            Serial.println(slide_pos);
            Serial.println("");
            show_image_example(slide_pos);
          }
          else if (three_interface_flag == 2)
          {
            Serial.print("show_scenario_example_pos-> slide_pos : ");
            Serial.println(slide_pos);
            Serial.println("");
            show_scenario_example_pos(slide_pos);
          }
        }
        break;
      case 4:
        //2级界面下滑
        if (peg_pos == 1)
        {
          slide_pos = slide_pos + 1;
          if (slide_pos > 2)
          {
            slide_pos = 2;
            return ;
          }
          Serial.print("show_home_menu_pos -> slide_pos : ");
          Serial.println(slide_pos);
          Serial.println("");
          show_home_menu_pos(slide_pos);
        }
        //3级界面下滑
        else if (peg_pos == 2)
        {
          if (three_interface_flag == 0)
          {
            slide_pos = slide_pos + 1;
            if (slide_pos > 3)
            {
              slide_pos = 3;
              return ;
            }
            Serial.print("show_description -> slide_pos : ");
            Serial.println(slide_pos);
            Serial.println("");
            show_description(slide_pos);
          }
          else if (three_interface_flag == 1)
          {
            slide_pos = slide_pos + 1;
            if (slide_pos > 6)
            {
              slide_pos = 6;
              return ;
            }
            Serial.print("show_image_example -> slide_pos : ");
            Serial.println(slide_pos);
            Serial.println("");
            show_image_example(slide_pos);
          }
          else if (three_interface_flag == 2)
          {
            slide_pos = slide_pos + 1;
            if (slide_pos > 4)
            {
              slide_pos = 4;
              return ;
            }
            Serial.print("show_scenario_example_pos -> slide_pos : ");
            Serial.println(slide_pos);
            Serial.println("");
            show_scenario_example_pos(slide_pos);
          }
        }
        break;
      case 5:
        //确定
        //2级界面确认
        if (peg_pos == 1)
        {
          Serial.println("ture into 2");
          if (slide_pos == 0)
          {
            Serial.println("into show description");
            Serial.print("show_description -> slide_pos : ");
            Serial.println(slide_pos);
            Serial.println("");
            clear_all1();
            show_description(slide_pos);
            slide_pos = 0;
            prv_menu_pos = 0;
            peg_pos = 2;
            three_interface_flag = 0;
          }
          else if (slide_pos == 1)
          {
            Serial.println("into show image example");
            clear_all1();
            show_image_example(0);
            prv_menu_pos = 1;
            slide_pos = 0;
            peg_pos = 2;
            three_interface_flag = 1;
          }
          else if (slide_pos == 2)
          {
            Serial.println("into show scenario example");
            clear_all();
            EPD_PartInit();
            EPD_ShowPicture(0, 0, EPD_W, EPD_H, gImage_scenario_home, WHITE);
            EPD_Display(ImageBW);
            EPD_Update();
            EPD_DeepSleep();

            slide_pos = 0;
            prv_menu_pos = 2;
            peg_pos = 2;
            three_interface_flag = 2;
          }
        }
        //3级界面确认
        else if (peg_pos == 2)
        {
          Serial.println("ture into 3");
          if (three_interface_flag == 2) //在灯光控制界面
          {
            if (slide_pos == 0)
            {
              show_scenario_example_ctl(slide_pos);
            }
            else if (slide_pos == 1)
            {
              show_scenario_example_ctl(slide_pos);
            }
            else if (slide_pos == 2)
            {
              show_scenario_example_ctl(slide_pos);
            }
            else if (slide_pos == 3)
            {
              show_scenario_example_ctl(slide_pos);
            }
            else if (slide_pos == 4)
            {
              show_scenario_example_ctl(slide_pos);
            }
          }
        }
        break;
      default:
        break;
    }
  }
  else if (KEY_SCAN() == 0 && test_flag == false)
  {
    delay(10);
    //    Serial.println("sleep_num +++  ....");
    sleep_num++;
    if (sleep_num == 6000)
    {
      EPD_HW_RESET();
      EPD_DeepSleep();

      sleep_num = 0;
      //Go to sleep now
      Serial.println("Going to sleep now ....");
      esp_deep_sleep_start();
    }
  }

  //  delay(60);
}

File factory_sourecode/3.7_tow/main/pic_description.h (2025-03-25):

const unsigned char gImage_description[12480] = { /* 0X01,0X01,0XF0,0X00,0XA0,0X01, */
0XFF,0XFF,0XFF,0XFF,0XFF,0XFF,0XFF,0XFF,0XFF,0XFF,0XFF,0XFF,0XFF,0XFF,0XFF,0XFF,
0XFF,0XFF,0XFF,0XFF,0XFF,0XFF,0XFF,0XFF,0XFF,0XFF,0XFF,0XFF,0XFF,0XFF,0XFF,0XFF,
0XFF,0XFF,0XFF,0XFF,0XFF,0XFF,0XFF,0XFF,0XFF,0XFF,0XFF,0XFF,0XFF,0XFF,0XFF,0XFF,
0XFF,0XFF,0XFF,0XFF,0XFF,0XFF,0XFF,0XFF,0XFF,0XFF,0XFF,0XFF,0XFF,0XFF,0XFF,0XFF,
0XFF,0XFF,0XFF,0XFF,0XFF,0XFF,0XFF,0XFF,0XFF,0XFF,0XFF,0XFF,0XFF,0XFF,0XFF,0XFF,
0XFF,0XFF,0XFF,0XFF,0XFF,0XFF,0XFF,0XFF,0XFF,0XFF,0XFF,0XFF,0XFF,0XFF,0XFF,0XFF,
0XFF,0XFF,0XFF,0XFF,0XFF,0XFF,0XFF,0XFF,0XFF,0XFF,0XFF,0XFF,0XFF,0XFF,0XFF,0XFF,
0XFF,0XFF,0XFF,0XFF,0XFF,0XFF,0XFF,0XFF,0XFF,0XFF,0XFF,0XFF,0XFF,0XFF,0XFF,0XFF,
0XFF,0XFF,0XFF,0XFF,0XFF,0XFF,0XFF,0XFF,0XFF,0XFF,0XFF,0XFF,0XFF,0XFF,0XFF,0XFF,
0XFF,0XFF,0XFF,0XFF,0XFF,0XFF,0XFF,0XFF,0XFF,0XFF,0XFF,0XFF,0XFF,0XFF,0XFF,0XFF,
0XFF,0XFF,0XFF,0XFF,0XFF,0XFF,0XFF,0XFF,0XFF,0XFF,0XFF,0XFF,0XFF,0XFF,0XFF,0XFF,
0XFF,0XFF,0XFF,0XFF,0XFF,0XFF,0XFF,0XFF,0XFF,0XFF,0XFF,0XFF,0XFF,0XFF,0XFF,0XFF,
0XFF,0XFF,0XFF,0XFF,0XFF,0XFF,0XFF,0XFF,0XFF,0XFF,0XFF,0XFF,0XFF,0XFF,0XFF,0XFF,
0XFF,0XFF,0XFF,0XFF,0XFF,0XFF,0XFF,0XFF,0XFF,0XFF,0XFF,0XFF,0XFF,0XFF,0XFF,0XFF,
0XFF,0XFF,0XFF,0XFF,0XFF,0XFF,0XFF,0XFF,0XFF,0XFF,0XFF,0XFF,0XFF,0XFF,0XFF,0XFF,
0XFF,0XFF,0XFF,0XFF,0XFF,0XFF,0XFF,0XFF,0XFF,0XFF,0XFF,0XFF,0XFF,0XFF,0XFF,0XFF,
0XFF,0XFF,0XFF,0XFF,0XFF,0XFF,0XE7,0XFF,0XFF,0XFF,0XFF,0XFF,0XFF,0XFF,0XFF,0XFF,
0XFF,0XFF,0XFF,0XFF,0XFF,0XFF,0XFF,0XFF,0XFF,0XFF,0XFF,0XFF,0XFF,0XFF,0XFF,0XFF,
0XFF,0XFF,0XFF,0XFF,0XFF,0XFF,0XFF,0XFF,0XFF,0XFF,0XFF,0XFF,0XFF,0XFF,0XFF,0XFF,
0XFF,0XFF,0XFF,0XFF,0XFF,0XFF,0XFF,0XFF,0XFF,0XFF,0XC3,0XFF,0XFF,0XFF,0XFF,0XFF,
0XFF,0XFF,0XFF,0XFF,0XFF,0XFF,0XFF,0XFF,0XFF,0XFF,0XFF,0XFF,0XFF,0XFF,0XFF,0XFF,
0XFF,0XFF,0XFF,0XFF,0XFF,0XFF,0XFF,0XFF,0XFF,0XFF,0XFF,0XFF,0XFF,0XFF,0XFF,0XFF,
0XFF,0XFF,0XFF,0XFF,0XFF,0XFF,0XFF,0XFF,0XFF,0XFF,0XFF,0XFF,0XFF,0XFF,0X81,0XFF,
0XFF,0XFF,0XFF,0XFF,0XFF,0XFF,0XFF,0XFF,0XFF,0XFF,0XFF,0XFF,0XFF,0XFF,0XFF,0XFF,
0XFF,0XFF,0XFF,0XFF,0XFF,0XFF,0XFF,0XFF,0XFF,0XFF,0XFF,0XFF,0XFF,0XFF,0XFF,0XFF,
0XFF,0XFF,0XFF,0XFF,0XFF,0XFF,0XFF,0XFF,0XFF,0XFF,0XFF,0XFF,0XFF,0XFF,0XFF,0XFF,
0XFF,0XFF,0X00,0XFF,0XFF,0XFF,0XFF,0XFF,0XFF,0XFF,0XFF,0XFF,0XFF,0XFF,0XFF,0XFF,
0XFF,0XFF,0XFF,0XFF,0XFF,0XFF,0XFF,0XFF,0XFF,0XFF,0XFF,0XFF,0XFF,0XFF,0XFF,0XFF,
0XFF,0XFF,0XFF,0XFF,0XFF,0XFF,0XFF,0XFF,0XFF,0XFF,0XFF,0XFF,0XFF,0XFF,0XFF,0XFF,
0XFF,0XFF,0XFF,0XFF,0XFF,0XFE,0X00,0X7F,0XFF,0XFF,0XFF,0XFF,0XFF,0XFF,0XFF,0XFF,
0XFF,0XFF,0XFF,0XFF,0XFF,0XFF,0XFF,0XFF,0XFF,0XFF,0XFF,0XFF,0XFF,0XFF,0XFF,0XFF,
0XFF,0XFF,0XFF,0XFF,0XFF,0XFF,0XFF,0XFF,0XFF,0XFF,0XFF,0XFF,0XFF,0XFF,0XFF,0XFF,
0XFF,0XFF,0XFF,0XFF,0XFF,0XFF,0XFF,0XFF,0XFF,0XFC,0X00,0X3F,0XFF,0XFF,0XFF,0XFF,
0XFF,0XFF,0XFF,0XFF,0XFF,0XFF,0XFF,0XFF,0XFF,0XFF,0XFF,0XFF,0XFF,0XFF,0XFF,0XFF,
0XFF,0XFF,0XFF,0XFF,0XFF,0XFF,0XFF,0XFF,0XFF,0XFF,0XFF,0XFF,0XFF,0XFF,0XFF,0XFF,
0XFF,0XFF,0XFF,0XFF,0XFF,0XFF,0XFF,0XFF,0XFF,0XFF,0XFF,0XFF,0XFF,0XF8,0X00,0X1F,
0XFF,0XFF,0XFF,0XFF,0XFF,0XFF,0XFF,0XFF,0XFF,0XFF,0XFF,0XFF,0XFF,0XFF,0XFF,0XFF,
0XFF,0XFF,0XFF,0XFF,0XFF,0XFF,0XFF,0XFF,0XFF,0XFF,0XFF,0XFF,0XFF,0XFF,0XFF,0XFF,
0XFF,0XFF,0XFF,0XFF,0XFF,0XFF,0XFF,0XFF,0XFF,0XFF,0XFF,0XFF,0XFF,0XFF,0XFF,0XFF,
0XFF,0XF0,0X00,0X0F,0XFF,0XFF,0XFF,0XFF,0XFF,0XFF,0XFF,0XFF,0XFF,0XFF,0XFF,0XFF,
0XFF,0XFF,0XFF,0XFF,0XFF,0XFF,0XFF,0XFF,0XFF,0XFF,0XFF,0XFF,0XFF,0XFF,0XFF,0XFF,
0XFF,0XFF,0XFF,0XFF,0XFF,0XFF,0XFF,0XFF,0XFF,0XFF,0XFF,0XFF,0XFF,0XFF,0XFF,0XFF,
0XFF,0XFF,0XFF,0XFF,0XFF,0XE0,0X00,0X07,0XFF,0XFF,0XFF,0XFF,0XFF,0XFF,0XFF,0XFF,
0XFF,0XFF,0XFF,0XFF,0XFF,0XFF,0XFF,0XFF,0XFF,0XFF,0XFF,0XFF,0XFF,0XFF,0XFF,0XFF,
0XFF,0XFF,0XFF,0XFF,0XFF,0XFF,0XFF,0XFF,0XFF,0XFF,0XFF,0XFF,0XFF,0XFF,0XFF,0XFF,
0XFF,0XFF,0XFF,0XFF,0XFF,0XFF,0XFF,0XFF,0XFF,0XC0,0X00,0X03,0XFF,0XFF,0XFF,0XFF,
0XFF,0XFF,0XFF,0XFF,0XFF,0XFF,0XFF,0XFF,0XFF,0XFF,0XFF,0XFF,0XFF,0XFF,0XFF,0XFF,
0XFF,0XFF,0XFF,0XFF,0XFF,0XFF,0XFF,0XFF,0XFF,0XFF,0XFF,0XFF,0XFF,0XFF,0XFF,0XFF,
0XFF,0XFF,0XFF,0XFF,0XFF,0XFF,0XFF,0XFF,0XFF,0XFF,0XFF,0XFF,0XFF,0XF8,0X00,0X1F,
0XFF,0XFF,0XFF,0XFF,0XFF,0XFF,0XFF,0XFF,0XFF,0XFF,0XFF,0XFF,0XFF,0XFF,0XFF,0XFF,
0XFF,0XFF,0XFF,0XFF,0XFF,0XFF,0XFF,0XFF,0XFF,0XFF,0XFF,0XFF,0XFF,0XFF,0XFF,0XFF,
0XFF,0XFF,0XFF,0XFF,0XFF,0XFF,0XFF,0XFF,0XFF,0XFF,0XFF,0XFF,0XFF,0XFF,0XFF,0XFF,
0XFF,0XF8,0X00,0X1F,0XFF,0XFF,0XFF,0XFF,0XFF,0XFF,0XFF,0XFF,0XFF,0XFF,0XFF,0XFF,
0XFF,0XFF,0XFF,0XFF,0XFF,0XFF,0XFF,0XFF,0XFF,0XFF,0XFF,0XFF,0XFF,0XFF,0XFF,0XFF,
0XFF,0XFF,0XFF,0XFF,0XFF,0XFF,0XFF,0XFF,0XFF,0XFF,0XFF,0XFF,0XFF,0XFF,0XFF,0XFF,
0XFF,0XFF,0XFF,0XFF,0XFF,0XF8,0X00,0X1F,0XFF,0XFF,0XFF,0XFF,0XFF,0XFF,0XFF,0XFF,
0XFF,0XFF,0XFF,0XFF,0XFF,0XFF,0XFF,0XFF,0XFF,0XFF,0XFF,0XFF,0XFF,0XFF,0XFF,0XFF,
0XFF,0XFF,0XFF,0XFF,0XFF,0XFF,0XFF,0XFF,0XFF,0XFF,0XFF,0XFF,0XFF,0XFF,0XFF,0XFF,
0XFF,0XFF,0XFF,0XFF,0XFF,0XFF,0XFF,0XFF,0XFF,0XF8,0X3C,0X1F,0XFF,0XFF,0XFF,0XFF,
0XFF,0XFF,0XFF,0XFF,0XFF,0XFF,0XFF,0XFF,0XFF,0XFF,0XFF,0XFF,0XFF,0XFF,0XFF,0XFF,
0XFF,0XFF,0XFF,0XFF,0XFF,0XFF,0XFF,0XFF,0XFF,0XFF,0XFF,0XFF,0XFF,0XFF,0XFF,0XFF,
0XFF,0XFF,0XFF,0XFF,0XFF,0XFF,0XFF,0XFF,0XFF,0XFF,0XFF,0XFF,0XFF,0XF8,0X3C,0X1F,
0XFF,0XFF,0XFF,0XFF,0XFF,0XFF,0XFF,0XFF,0XFF,0XFF,0XFF,0XFF,0XFF,0XFF,0XFF,0XFF,
0XFF,0XFF,0XFF,0XFF,0XFF,0XFF,0XFF,0XFF,0XFF,0XFF,0XFF,0XFF,0XFF,0XFF,0XFF,0XFF,
0XFF,0XFF,0XFF,0XFF,0XFF,0XFF,0XFF,0XFF,0XFF,0XFF,0XFF,0XFF,0XFF,0XFF,0XFF,0XFF,
0XFF,0XF8,0X3C,0X1F,0XFF,0XFF,0XFF,0XFF,0XFF,0XFF,0XFF,0XFF,0XFF,0XFF,0XFF,0XFF,
0XFF,0XFF,0XFF,0XFF,0XFF,0XFF,0XFF,0XFF,0XFF,0XFF,0XFF,0XFF,0XFF,0XFF,0XFF,0XFF,
0XFF,0XFF,0XFF,0XFF,0XFF,0XFF,0XFF,0XFF,0XFF,0XFF,0XFF,0XFF,0XFF,0XFF,0XFF,0XFF,
0XFF,0XFF,0XFF,0XFF,0XFF,0XF8,0X3C,0X1F,0XFF,0XFF,0XFF,0XFF,0XFF,0XFF,0XFF,0XFF,
0XFF,0XFF,0XFF,0XFF,0XFF,0XFF,0XFF,0XFF,0XFF,0XFF,0XFF,0XFF,0XFF,0XFF,0XFF,0XFF,
0XFF,0XFF,0XFF,0XFF,0XFF,0XFF,0XFF,0XFF,0XFF,0XFF,0XFF,0XFF,0XFF,0XFF,0XFF,0XFF,
0XFF,0XFF,0XFF,0XFF,0XFF,0XFF,0XFF,0XFF,0XFF,0XF8,0X3C,0X1F,0XFF,0XFF,0XFF,0XFF,
0XFF,0XFF,0XFF,0XFF,0XFF,0XFF,0XFF,0XFF,0XFF,0XFF,0XFF,0XFF,0XFF,0XFF,0XFF,0XFF,
0XFF,0XFF,0XFF,0XFF,0XFF,0XFF,0XFF,0XFF,0XFF,0XFF,0XFF,0XFF,0XFF,0XFF,0XFF,0XFF,
0XFF,0XFF,0XFF,0XFF,0XFF,0XFF,0XFF,0XFF,0XFF,0XFF,0XFF,0XFF,0XFF,0XF8,0X3C,0X1F,
0XFF,0XFF,0XFF,0XFF,0XFF,0XFF,0XFF,0XFF,0XFF,0XFF,0XFF,0XFF,0XFF,0XFF,0XFF,0XFF,
0XFF,0XFF,0XFF,0XFF,0XFF,0XFF,0XFF,0XFF,0XFF,0XFF,0XFF,0XFF,0XFF,0XFF,0XFF,0XFF,
0XFF,0XFF,0XFF,0XFF,0XFF,0XFF,0XFF,0XFF,0XFF,0XFF,0XFF,0XFF,0XFF,0XFF,0XFF,0XFF,
0XFF,0XF8,0X3C,0X1F,0XFF,0XFF,0XFF,0XFF,0XFF,0XFF,0XFF,0XFF,0XFF,0XFF,0XFF,0XFF,
0XFF,0XFF,0XFF,0XFF,0XFF,0XFF,0XFF,0XFF,0XFF,0XFF,0XFF,0XFF,0XFF,0XFF,0XFF,0XFF,
0XFF,0XFF,0XFF,0XFF,0XFF,0XFF,0XFF,0XFF,0XFF,0XFF,0XFF,0XFF,0XFF,0XFF,0XFF,0XFF,
0XFF,0XFF,0XFF,0XFF,0XFF,0XFF,0XFF,0XFF,0XFF,0XFF,0XFF,0XFF,0XFF,0XFF,0XFF,0XFF,
0XFF,0XFF,0XFF,0XFF,0XFF,0XFF,0XFF,0XFF,0XFF,0XFF,0XFF,0XFF,0XFF,0XFF,0XFF,0XFF,
0XFF,0XFF,0XFF,0XFF,0XFF,0XFF,0XFF,0XFF,0XFF,0XFF,0XFF,0XFF,0XFF,0XFF,0XFF,0XFF,
0XFF,0XFF,0XFF,0XFF,0XFF,0XFF,0XFF,0XFF,0XFF,0XFF,0XFF,0XFF,0XFF,0XFF,0XFF,0XFF,
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
